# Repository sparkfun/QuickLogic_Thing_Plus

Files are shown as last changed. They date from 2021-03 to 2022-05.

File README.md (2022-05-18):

SparkFun QuickLogic Thing Plus - EOS S3
========================================

SparkFun QuickLogic Thing Plus - EOS S3 (https://www.sparkfun.com/products/17273)

[*SparkFun QuickLogic Thing Plus - EOS S3 (DEV-17273)*](https://www.sparkfun.com/products/17273)

The SparkFun QuickLogic Thing Plus [EOS&trade; S3](https://www.quicklogic.com/products/eos-s3/), is a small form factor system ideal for enabling the next generation of low-power Machine Learning (ML) devices. The QuickLogic Thing Plus is powered by QuickLogic’s EOS S3, the first eFPGA-enabled Arm Cortex&copy;-M4F MCU to be fully supported with Zephyr RTOS and FreeRTOS. Unlike other development boards which are based on proprietary hardware and software tools, the QuickLogic Things Plus is based on 100% open source hardware, compatible with the Feather form factor, and is built around 100% open source software (with support for FreeRTOS, Zephyr, nMingen, Docker, and SymbiFlow). 

Between the onboard LiPo battery connector and charging circuitry, wake-on-sound PDM microphone, and low-power, three-axis accelerometer, this Thing Plus board is ideal for wearable, voice, gesture sensing applications. The strong firmware support for the microphone and accelerator make it easy to move sensor data into the embedded FPGA. From there, you can use SensiML, TensorFlow Lite, or other tools to train and run embedded machine learning algorithms specific to your application. The board also includes a Qwiic connector to quickly interface with an ecosystem of 150+ I<sup>2</sup>C-compatible boards such as sensors, RFID readers, displays, keypads, and relays.

Repository Contents
-------------------

* **/Hardware** - Cadence design file (.brd) and scehmatic

Documentation
--------------
 
* **[Hookup Guide](https://learn.sparkfun.com/tutorials/1791)** - Basic hookup guide for the SparkFun QuickLogic EOS S3.
* **[SparkFun Graphical Datasheets](https://github.com/sparkfun/Graphical_Datasheets)** - Graphical Datasheets for various SparkFun products.

Product Versions
----------------

* [DEV-17273](https://www.sparkfun.com/products/17273) 

Version History
---------------

* v2.0 - Initial release

License Information
-------------------

This product is _**open source**_! 

Please review the LICENSE.md file for license information. 

If you have any questions or concerns on licensing, please contact technical support on our [SparkFun forums](https://forum.sparkfun.com/viewforum.php?f=152).

Distributed as-is; no warranty is given.

- Your friends at SparkFun.

_<COLLABORATION CREDIT>_

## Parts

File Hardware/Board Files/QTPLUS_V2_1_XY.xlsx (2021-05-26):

Placed Component Report
C:/PCBs/QT+/OrCAD/QTPLUS_V2.1/Board/QTPLUS_V2_1.brd
Sat May 08 19:20:52 2021
Total Placed Components: 103
REFDES | COMP_DEVICE_TYPE | COMP_VALUE | COMP_TOL | SYM_NAME | SYM_X | SYM_Y | SYM_ROTATE | SYM_MIRROR
AC1 | LIS2DH12TR_LGA50P200X200100-12N | LIS2DH12TR |  | LGA50P200X200100-12N | 29.4432 | 14.7132 | 0 | NO
C1 | CAP NP_SMD_0603_4.7UF | 4.7uF |  | SMD_0603 | 22.7235 | 11.8712 | 90 | NO
C2 | CAP NP_SMD_0402_100PF | 100pF |  | SMD_0402 | 16.5643 | 10.5281 | 180 | NO
C3 | CAP NP_SMD_0603_22UF | 22uF |  | SMD_0603 | 25.1024 | 9.9331 | 180 | NO
C4 | CAP NP_SMD_0603_4.7UF | 4.7uF |  | SMD_0603 | 12.7865 | 12.6092 | 270 | NO
C5 | CAP NP_SMD_0402_1UF | 1uF |  | SMD_0402 | 6.8619 | 21.7307 | 270 | NO
C6 | CAP NP_SMD_0402_0.1UF | 0.1uF |  | SMD_0402 | 37.9049 | 15.3563 | 90 | NO
C7 | CAP NP_SMD_0402_0.1UF | 0.1uF |  | SMD_0402 | 31.9331 | 15.2549 | 180 | NO
C8 | CAP NP_SMD_0603_4.7UF | 4.7uF |  | SMD_0603 | 37.8644 | 17.9335 | 180 | NO
C9 | CAP NP_SMD_0603_4.7UF | 4.7uF |  | SMD_0603 | 36.3514 | 17.9399 | 180 | NO
C10 | CAP NP_SMD_0402_0.1UF | 0.1uF |  | SMD_0402 | 39.8749 | 9.2727 | 90 | NO
C11 | CAP NP_SMD_0402_0.1UF | 0.1uF |  | SMD_0402 | 34.8851 | 7.4013 | 270 | NO
C12 | CAP NP_SMD_0402_12 PF | 12 pF |  | SMD_0402 | 41.8161 | 11.2781 | 180 | NO
C13 | CAP NP_SMD_0402_12 PF | 12 pF |  | SMD_0402 | 41.8075 | 13.1119 | 0 | NO
C14 | CAP NP_SMD_0402_0.1UF | 0.1uF |  | SMD_0402 | 20.3017 | 3.9249 | 180 | NO
C15 | CAP NP_SMD_0603_4.7UF | 4.7uF |  | SMD_0603 | 9.024 | 14.6535 | 180 | NO
C16 | CAP NP_SMD_0402_0.1UF | 0.1uF |  | SMD_0402 | 44.5349 | 13.4803 | 90 | NO
C17 | CAP NP_SMD_0402_0.1UF | 0.1uF |  | SMD_0402 | 46.8285 | 18.4229 | 90 | NO
C18 | CAP NP_SMD_0402_0.1UF | 0.1uF |  | SMD_0402 | 52.2349 | 14.6905 | 90 | NO
D1 | MBR0520LT3G_SOD-323_S_PMEG4005E | PMEG4005EJ,115 |  | SOD-323_S | 22.4511 | 13.1983 | 180 | NO
D2 | TPD2EUSB30DRTR_TPD2EUSB_SOTFL35 | TPD2EUSB30DRTR |  | TPD2EUSB_SOTFL35P100X50-3N | 9.5884 | 11.4381 | 180 | NO
D3 | TPD2EUSB30DRTR_TPD2EUSB_SOTFL35 | TPD2EUSB30DRTR |  | TPD2EUSB_SOTFL35P100X50-3N | 49.338 | 13.4719 | 0 | NO
D4 | TPD2EUSB30DRTR_TPD2EUSB_SOTFL35 | TPD2EUSB30DRTR |  | TPD2EUSB_SOTFL35P100X50-3N | 46.1052 | 6.7781 | 180 | NO
D5 | ESD9B3_3ST5G_SOD-323_S_SD05C.TC | SD05C.TCT |  | SOD-323_S | 52.4671 | 16.4517 | 0 | NO
FD1 | T POINT R_1_FID_IN025X033_FIDUC | fiducial |  | FID_IN025X033 | 1.545 | 17.545 | 0 | NO
FD2 | T POINT R_1_FID_IN025X033_FIDUC | fiducial |  | FID_IN025X033 | 69.045 | 6.845 | 0 | NO
H1 | MH_0_MH2_5MM_MH | MH |  | MH2_5MM | 55.7727 | 20.3481 | 0 | NO
H2 | MH_0_MH2_5MM_MH | MH |  | MH2_5MM | 2.54 | 20.3481 | 0 | NO
H3 | MH_0_MH2_5MM_MH | MH |  | MH2_5MM | 2.54 | 2.5681 | 0 | NO
H4 | MH_0_MH2_5MM_MH | MH |  | MH2_5MM | 55.7837 | 2.5681 | 0 | NO
IC1 | TPS62821DLCR_SON50P150X200X100- | TPS62821DLCR |  | SON50P150X200X100-8N | 19.9532 | 10.4252 | 0 | NO
IC2 | MCP73831T_2ACI_OT_MCP73831T_SOT | MCP73831T_2ACI_OT |  | MCP73831T_SOT95P270X145-5N | 12.1481 | 15.6992 | 90 | NO
IC3 | GD25Q16CWIGR_SON127P500X600X80- | GD25Q16CWIGR |  | SON127P500X600X80-9N-D | 24.423 | 5.4013 | 180 | NO
IC4 | 2N7002PV_115_SOTFL50P160X60-6N_ | 2N7002PV_115 |  | SOTFL50P160X60-6N | 27.5672 | 10.4381 | 180 | NO
IC5 | 2N7002PV_115_SOTFL50P160X60-6N_ | 2N7002PV_115 |  | SOTFL50P160X60-6N | 27.5672 | 12.5681 | 180 | NO
J1 | S2B-PH-SM4-TBLFSN_JST_S2B-PH-SM | S2B-PH-SM4-TBLFSN |  | JST_S2B-PH-SM4-TBLFSN | 18.17 | 18.33 | 180 | NO
J2 | CON2_CN2_CON2 | CON2 |  | CN2 | 67.0809 | 17.6972 | 90 | NO
J3 | CON2_CN2_CON2 | CON2 |  | CN2 | 67.0809 | 3.1872 | 90 | NO
J4 | 4208_QWIIC_PRT-14417_4208_QWIIC | Qwiic_PRT-14417 / 4208 |  | QWIIC_PRT-14417_4208 | 66.96 | 11.44 | 90 | NO
J5 | USB4105-GF-A_GCT_USB4105-GF-A_U | USB4105-GF-A |  | GCT_USB4105-GF-A | 2.61 | 11.42 | 270 | NO
J6 | CON16_CN16_CON16 | CON16 |  | CN16 | 51.94 | 1.27 | 0 | YES
J7 | 62201021121_CON_2X5_SMA_1P27_62 | 62201021121 |  | CON_2X5_SMA_1P27 | 51.55 | 8.9 | 180 | NO
J8 | CON18A_0_CN2X9D_FEMALE_CON18A | CON18A |  | CN2X9D_FEMALE | 59.556 | 21.591 | 90 | YES
J9 | CON12_CN12_CON12 | CON12 |  | CN12 | 24.01 | 21.59 | 180 | YES
L1 | DFE201610E_R47M=P2_DFE201610E-R | DFE201610E_R47M=P2 |  | DFE201610E-R47M_1285ASH1R0MP2 | 22.9984 | 9.5951 | 0 | NO
LED1 | APT1608SYCK_LEDC1608X85N_APT160 | APT1608SYCK |  | LEDC1608X85N | 9.1349 | 21.1084 | 90 | NO
LED2 | CON4A_P-LCC-4_67-23/R6GHBHC-B06 | 67-23/R6GHBHC-B06/2T |  | P-LCC-4 | 24.4 | 16.8 | 90 | NO
MIC_PORT | T POINT R_0P75_HOLE_T POINT R | T POINT R |  | 0P75_HOLE | 45.65 | 11.2 | 0 | NO
Q1 | NX3008CBKV_0_NX3008CBKV_SOTFL50 | NX3008CBKV_115 |  | NX3008CBKV_SOTFL50P160X60-6N | 11.8096 | 9.4519 | 0 | NO
Q2 | 2N7002KW_SOT65P210X110-3N_2N700 | 2N7002KW |  | SOT65P210X110-3N | 6.8352 | 19.4236 | 270 | NO
R1 | RESISTOR_SMD_0402_1M5 | 1M5 |  | SMD_0402 | 19.974 | 12.0801 | 270 | NO
R2 | RESISTOR_SMD_0402_453K | 453K |  | SMD_0402 | 15.1851 | 10.5383 | 0 | NO
R3 | RESISTOR_SMD_0402_100K | 100K |  | SMD_0402 | 13.7793 | 10.5417 | 180 | NO
R4 | RESISTOR_SMD_0402_100K | 100K |  | SMD_0402 | 18.0911 | 10.5717 | 180 | NO
R5 | RESISTOR_SMD_0402_200K | 200K |  | SMD_0402 | 11.2061 | 7.3183 | 180 | NO
R6 | RESISTOR_SMD_0402_10K | 10K |  | SMD_0402 | 9.7049 | 9.4483 | 0 | NO
R7 | RESISTOR_SMD_0402_100K | 100K |  | SMD_0402 | 9.6849 | 7.3183 | 0 | NO
R8 | RESISTOR_SMD_0402_1K5 | 1K5 |  | SMD_0402 | 9.1357 | 18.4545 | 180 | NO
R9 | RESISTOR_SMD_0402_4K7 | 4K7 |  | SMD_0402 | 8.8217 | 16.9425 | 90 | NO
R10 | RESISTOR_SMD_0402_10K | 10K |  | SMD_0402 | 64.4207 | 19.9785 | 180 | NO
R11 | RESISTOR_SMD_0402_10K | 10K |  | SMD_0402 | 64.3597 | 5.3685 | 180 | NO
R12 | RESISTOR_SMD_0402_10K | 10K |  | SMD_0402 | 64.4207 | 17.6385 | 180 | NO
R13 | RESISTOR_SMD_0402_10K | 10K |  | SMD_0402 | 64.3597 | 3.3315 | 180 | NO
R14 | RESISTOR_SMD_0402_10K | 10K |  | SMD_0402 | 33.3599 | 17.2951 | 0 | NO
R15 | RESISTOR_SMD_0402_10K | 10K |  | SMD_0402 | 32.0831 | 17.2915 | 0 | NO
R16 | RESISTOR_SMD_0402_1K5 | 1K5 |  | SMD_0402 | 30.4983 | 12.4569 | 270 | NO
R17 | RESISTOR_SMD_0402_22E | 22E |  | SMD_0402 | 30.4983 | 11.1623 | 270 | NO
R18 | RESISTOR_SMD_0402_22E | 22E |  | SMD_0402 | 30.4983 | 8.3641 | 270 | NO
R19 | RESISTOR_SMD_0402_1K5 | 1K5 |  | SMD_0402 | 30.4983 | 9.7487 | 270 | NO
R20 | RESISTOR_SMD_0402_10K | 10K |  | SMD_0402 | 20.3017 | 5.8249 | 180 | NO
R21 | RESISTOR_SMD_0402_10K | 10K |  | SMD_0402 | 28.6945 | 7.0849 | 180 | NO
R22 | RESISTOR_SMD_0402_10K | 10K |  | SMD_0402 | 12.5283 | 5.4143 | 270 | NO
R23 | RESISTOR_SMD_0402_10K | 10K |  | SMD_0402 | 12.6543 | 7.3183 | 0 | NO
R24 | RESISTOR_SMD_0402_100E | 100E |  | SMD_0402 | 26.6633 | 15.8383 | 0 | NO
R25 | RESISTOR_SMD_0402_100E | 100E |  | SMD_0402 | 25.4685 | 12.7417 | 180 | NO
R26 | RESISTOR_SMD_0402_220E | 220E |  | SMD_0402 | 26.7279 | 18.5483 | 0 | NO
R28 | RESISTOR_SMD_0402_100E | 100E |  | SMD_0402 | 43.7783 | 8.2003 | 270 | NO
R29 | RESISTOR_SMD_0402_4K7 | 4K7 |  | SMD_0402 | 49.3417 | 16.4361 | 90 | NO
R30 | RESISTOR_SMD_0402_10K | 10K |  | SMD_0402 | 49.3417 | 17.8503 | 90 | NO
R31 | RESISTOR_SMD_0402_4K7 | 4K7 |  | SMD_0402 | 49.3417 | 15.1243 | 90 | NO
R32 | RESISTOR_SMD_0402_22E | 22E |  | SMD_0402 | 30.9241 | 4.4183 | 0 | NO
R33 | RESISTOR_SMD_0402_22E | 22E |  | SMD_0402 | 32.3523 | 4.4183 | 0 | NO
R34 | RESISTOR_SMD_0402_10K | 10K |  | SMD_0402 | 46.2483 | 8.2385 | 270 | NO
R35 | RESISTOR_SMD_0402_10K | 10K |  | SMD_0402 | 46.2383 | 4.9567 | 270 | NO
R36 | RESISTOR_SMD_0402_22E | 22E |  | SMD_0402 | 28.1405 | 19.1583 | 0 | NO
R38 | RESISTOR_SMD_0402_22E | 22E |  | SMD_0402 | 30.7969 | 18.5183 | 0 | NO
R39 | RESISTOR_SMD_0402_100K | 100K |  | SMD_0402 | 29.5175 | 19.15 | 180 | NO
RN1 | EXB_0_EXB2HV220JV_EXB_2HV220JV | EXB_2HV220JV |  | EXB2HV220JV | 55.7132 | 14.7021 | 270 | NO
RN2 | EXB_0_EXB2HV220JV_EXB_2HV220JV | EXB_2HV220JV |  | EXB2HV220JV | 41.5547 | 5.3632 | 0 | NO
RN3 | EXB_0_EXB2HV220JV_EXB_2HV220JV | EXB_2HV220JV |  | EXB2HV220JV | 56.5632 | 8.9985 | 270 | NO
RN4 | EXB_0_EXB2HV220JV_EXB_2HV220JV | EXB_2HV220JV |  | EXB2HV220JV | 42.77 | 17.6 | 0 | NO
S1 | KMR221GLFS_KMR2_1_KMR221GLFS | KMR221GLFS |  | KMR2_1 | 16.23 | 7.98 | 0 | NO
S2 | KMR221GLFS_KMR2_1_KMR221GLFS | KMR221GLFS |  | KMR2_1 | 16.23 | 4.28 | 0 | NO
TP1 | T POINT R_TPS50_T POINT R | T POINT R |  | TPS50 | 19.3578 | 20.2515 | 0 | YES
TP2 | T POINT R_TPS50_T POINT R | T POINT R |  | TPS50 | 16.7946 | 20.2215 | 0 | YES
TP3 | T POINT R_TPS50_T POINT R | T POINT R |  | TPS50 | 14.2814 | 20.2215 | 0 | YES
TP4 | T POINT R_TPS50_T POINT R | T POINT R |  | TPS50 | 10.4464 | 5.4032 | 90 | YES
TP5 | T POINT R_TPS50_T POINT R | T POINT R |  | TPS50 | 65.05 | 1.2 | 0 | YES
TP6 | T POINT R_TPS50_T POINT R | T POINT R |  | TPS50 | 65.05 | 3.744 | 0 | YES
TP7 | T POINT R_TPS50_T POINT R | T POINT R |  | TPS50 | 10.42 | 2.835 | 90 | YES
U1 | EOS_S3B_VBGA64_VBGA64_3M5X3M5X0 | EOS_S3B_VBGA64 |  | VBGA64_3M5X3M5X0M6 | 35.05 | 11.34 | 0 | NO
U2 | AAS-B1100-H01_0_VM3011_VM3011 | VM3011 |  | VM3011 | 45.6468 | 11.1981 | 180 | NO
Y2 | ABS07-32768KHZ-T_XTAL_ABS07-327 | ABS07-32768KHZ-T |  | XTAL_ABS07-32768KHZ-T | 39.9668 | 12.2196 | 90 | NO

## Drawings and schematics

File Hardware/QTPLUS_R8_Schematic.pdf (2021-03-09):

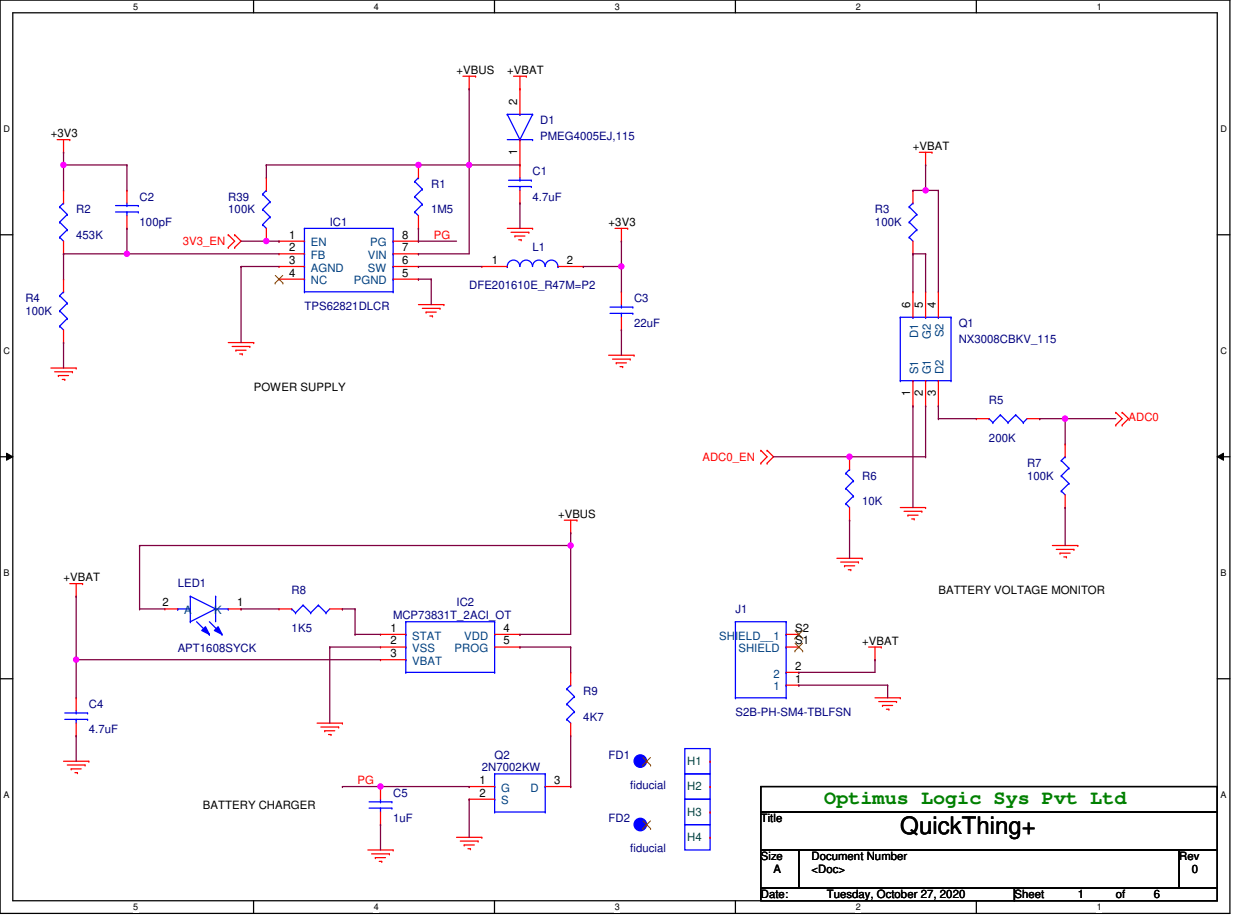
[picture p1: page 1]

Optimus Logic Sys Pvt Ltd

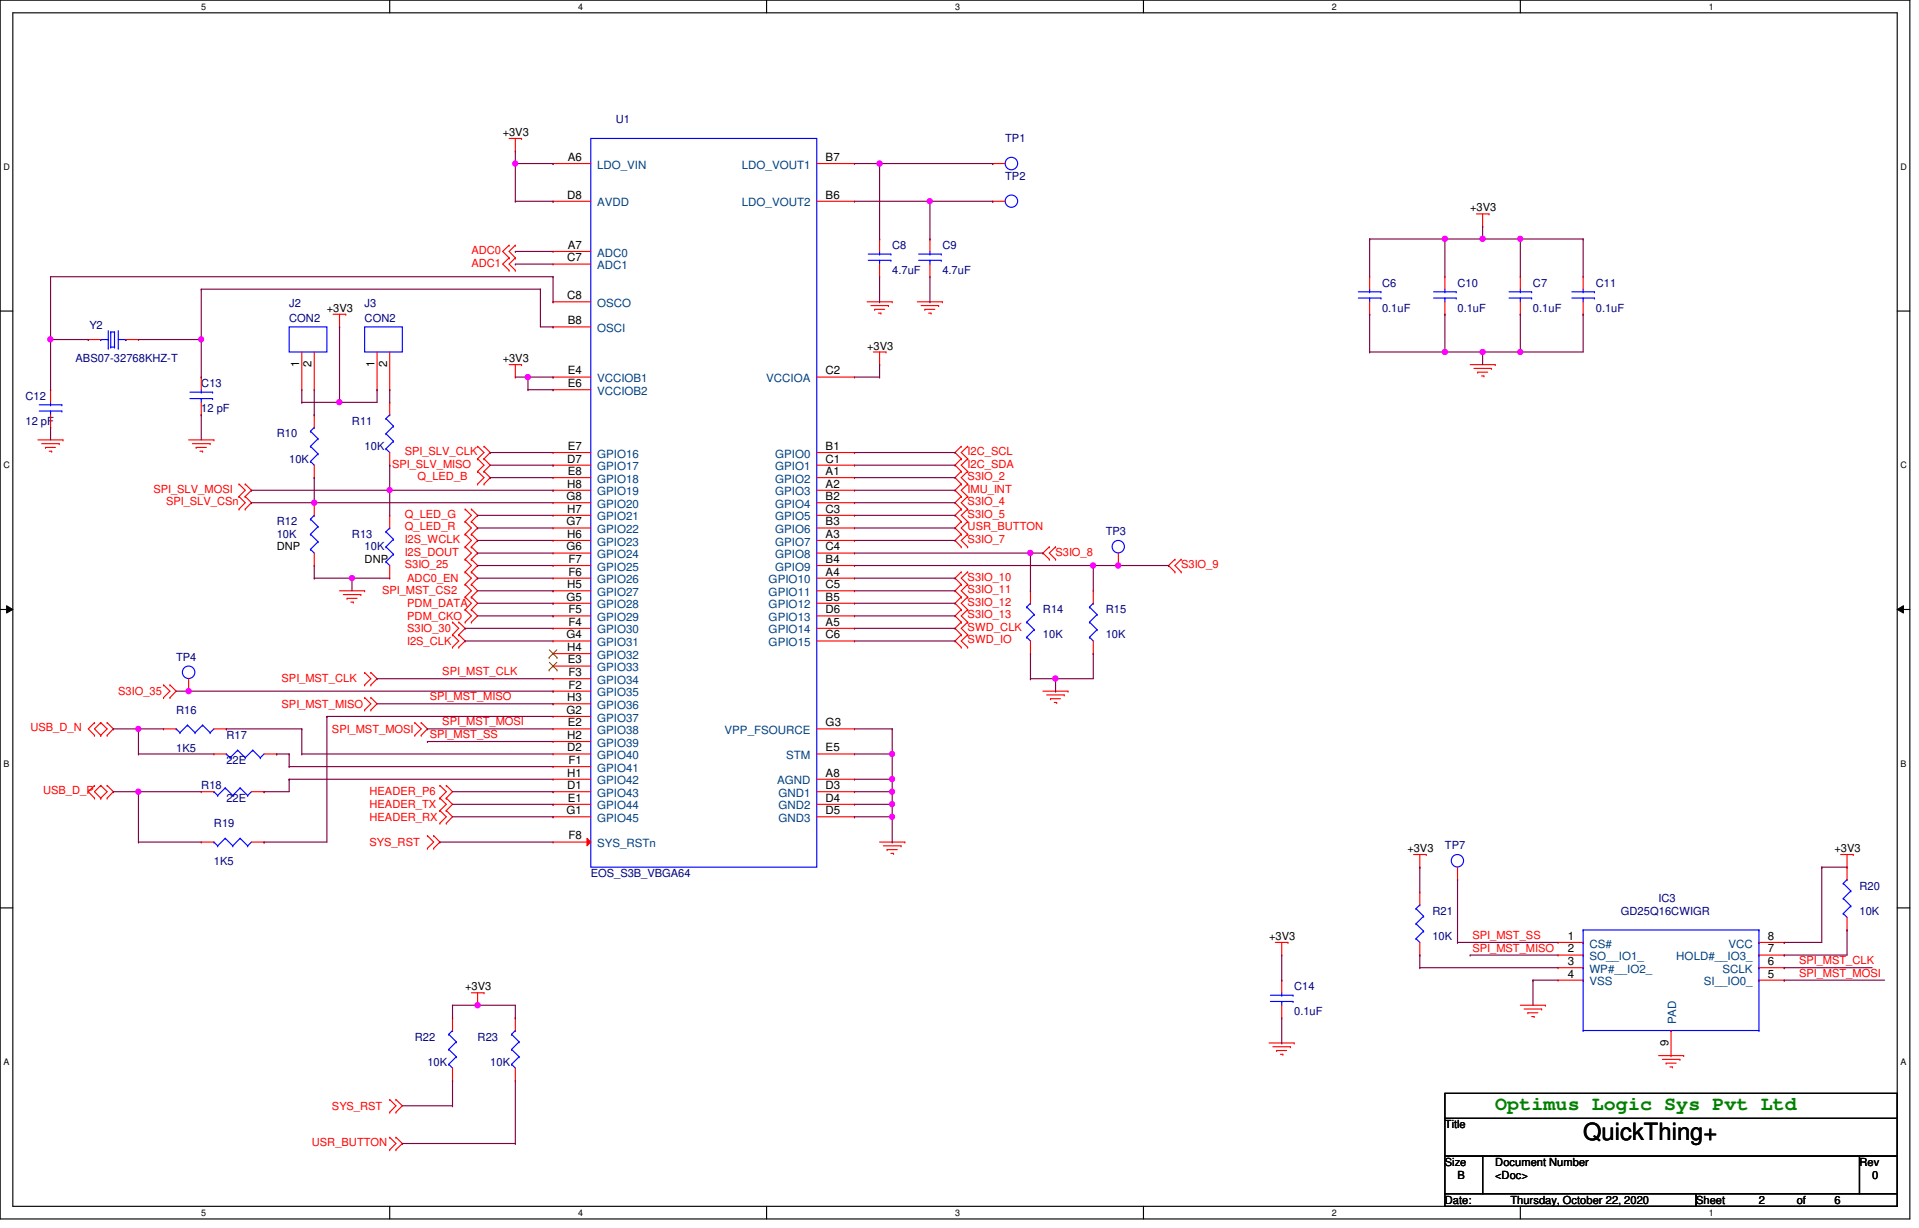
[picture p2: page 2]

Optimus Logic Sys Pvt Ltd

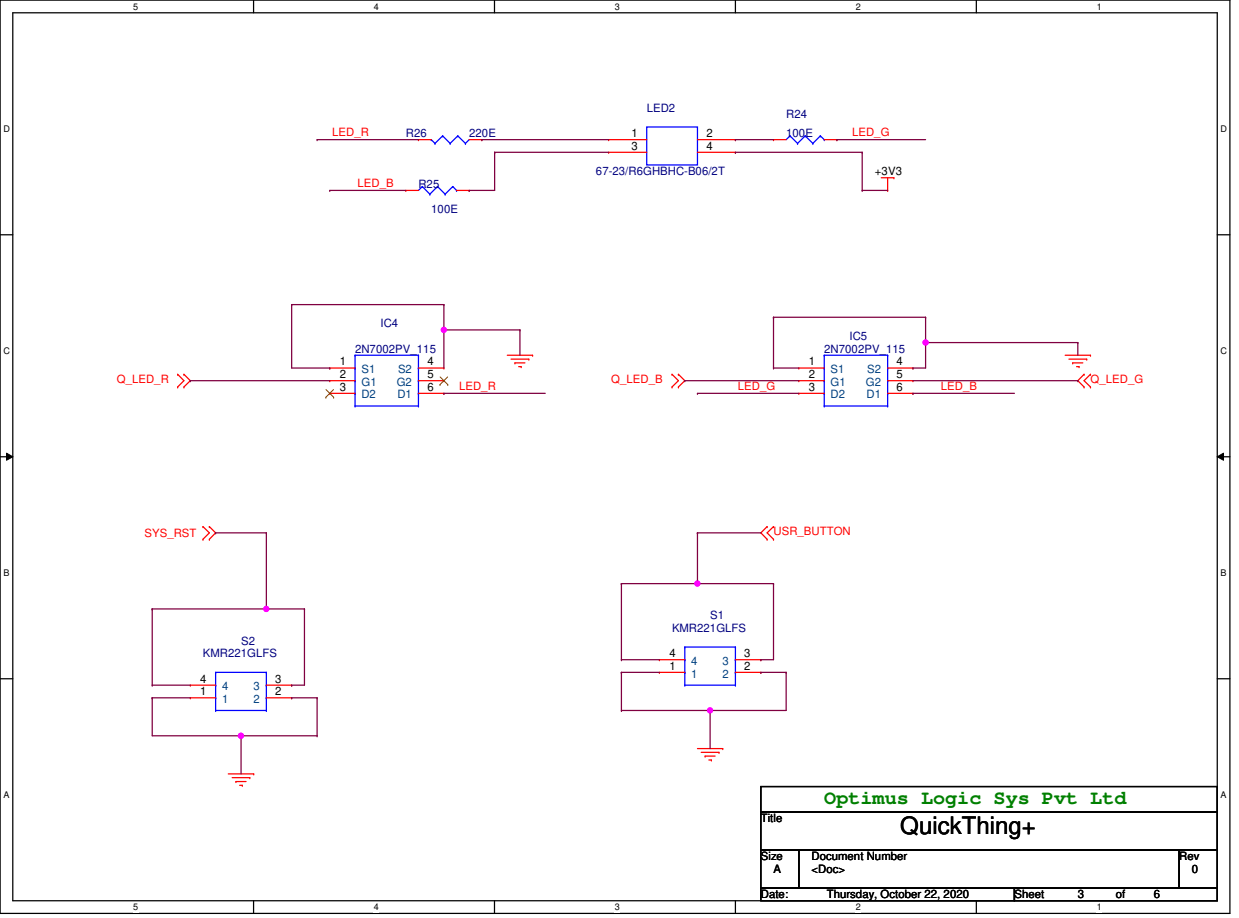
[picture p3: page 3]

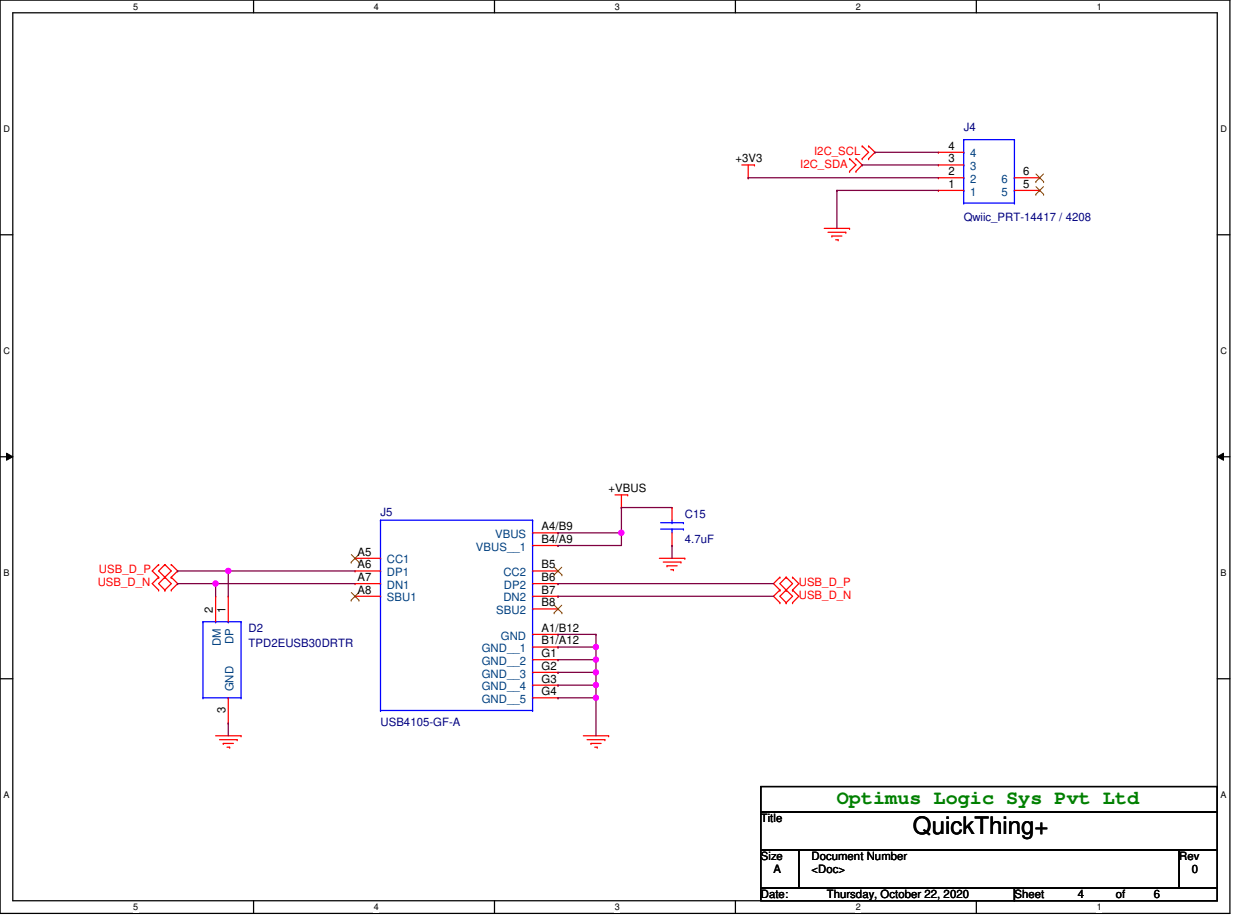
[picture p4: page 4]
Optimus Logic Sys Pvt Ltd; +VBUS; I2C_SCL I2C_SDA; USB_D_N; USB_D_P; Title; QuickThing+; Thursday, October 22, 2020; USB4105-GF-A; CC1 A5 DP1 A6 DN1 A7 SBU1 A8; VBUS; SBU2; GND; VBUS__1; GND__1; GND__2; GND__3; GND__4; GND__5; D2 DP TPD2EUSB30DRTR; Qwiic_PRT-14417 / 4208

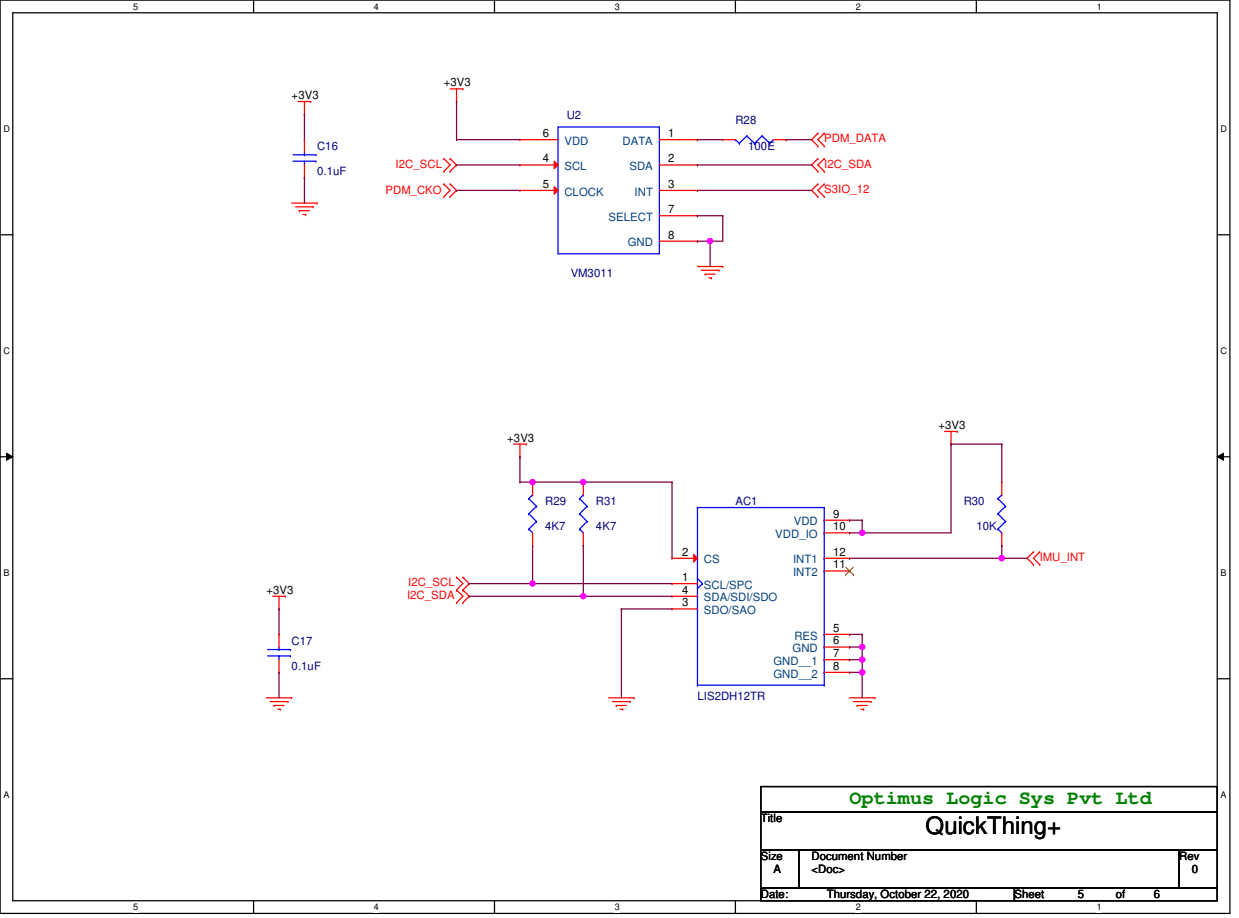
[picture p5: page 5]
Optimus Logic Sys Pvt Ltd; PDM_DATA; PDM_CKO; I2C_SCL; I2C_SDA; IMU_INT; I2C_SCL I2C_SDA; Title; QuickThing+; Thursday, October 22, 2020; LIS2DH12TR; SCL/SPC 1; SDO/SAO 3; SDA/SDI/SDO 4; RES; GND; GND__1; GND__2; VDD; VDD_IO; INT2; 11 INT1; DATA; SDA; INT; SCL 4; VDD 6; SELECT; CLOCK 5

10 | 10 11 | 11 12 | 12 13 | 13 14 | 14 15 | 15
10 | 10 11 | 11 12 | 12 13 | 13 14 | 14 15 | 15

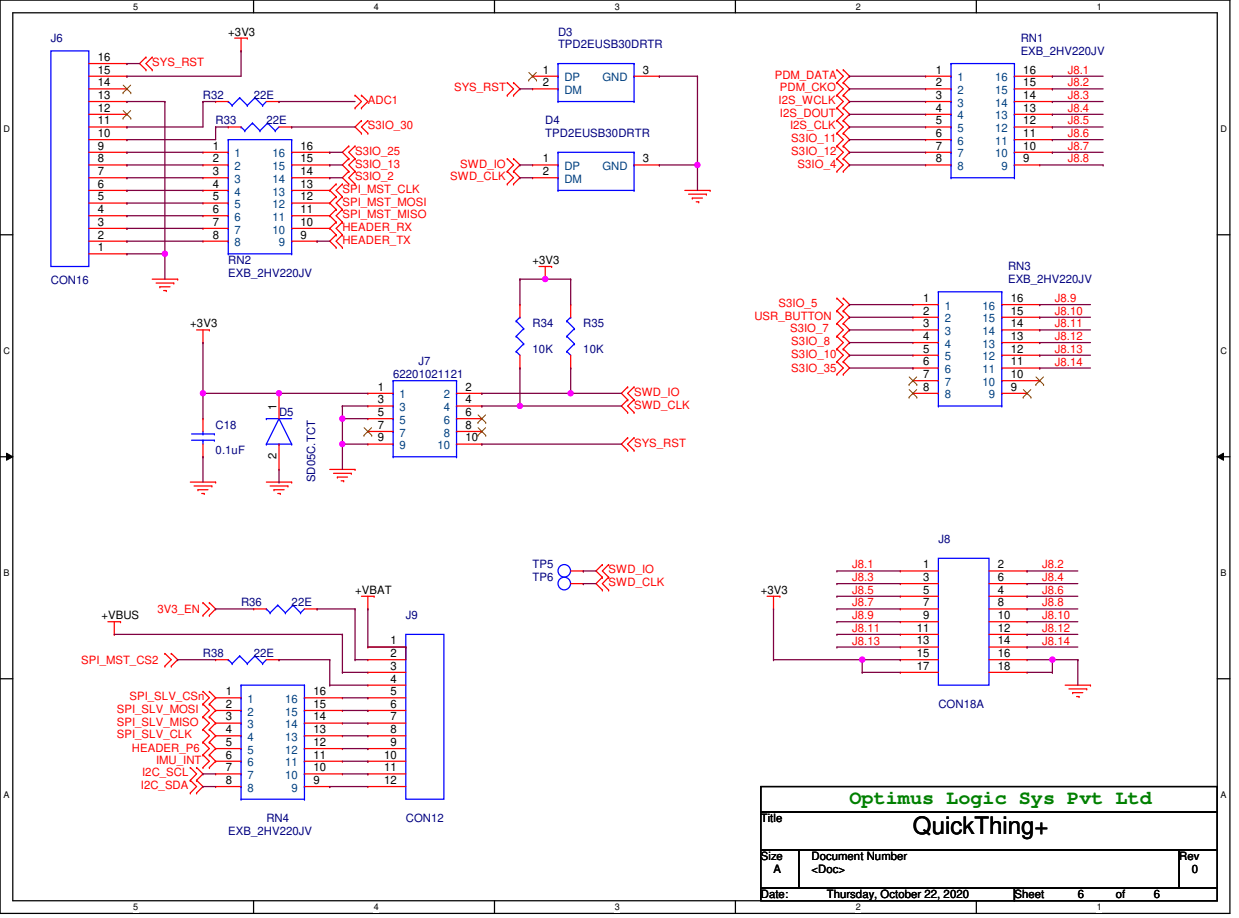
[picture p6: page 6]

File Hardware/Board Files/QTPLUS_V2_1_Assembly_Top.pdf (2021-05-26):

# ART FILM - ASSY_TOP

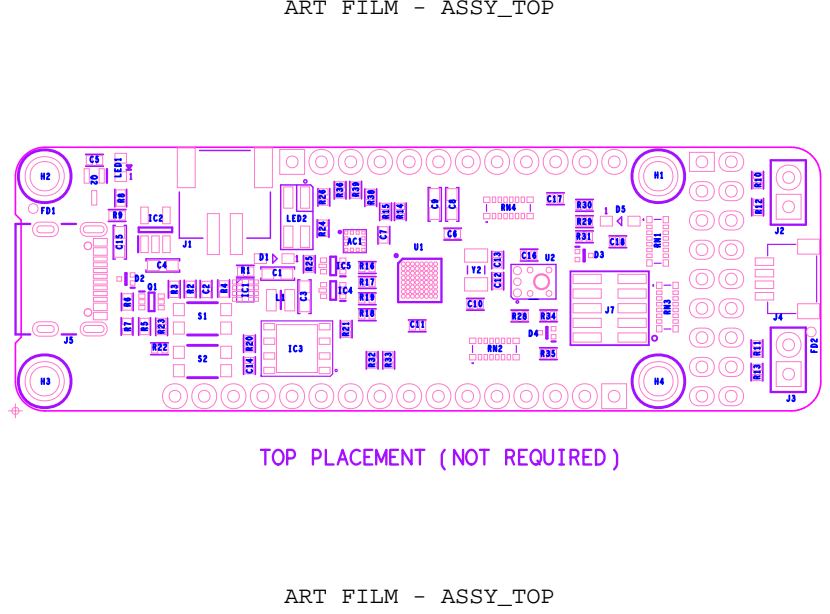
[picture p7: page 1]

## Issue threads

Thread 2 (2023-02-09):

Three broken boards

JsGraaf, 2023-02-09:
Hello,

I have three QuickLogic Thing Plusses and none of them work. Two of the three boards give a blue flashing light which turns off after 5 seconds but they can't enter programming mode (no green breathing light after pressing the usr button within 5 seconds). The other board shows a red led when powering up, which promply turns off. I have tried reflashing the bootloader with openocd and an STLinkv2, as stated on https://forum.quicklogic.com/viewtopic.php?t=29, however, the STLink is unable to restart the board after programming, failing the entire operation. I have not been able to find any resources from Sparkfun on recovering these boards and there is a "dead" thread on the forum that never got a reply.

I'm hoping that someone here can help.

Funda, 2023-02-09:
JsGraaf, thank you for reaching out here. I am investigating the issue today and will hopefully have a response to the forum thread by the end of the day. I see you replied to the thread. Let's continue the conversation there: https://forum.sparkfun.com/viewtopic.php?f=176&t=56658&p=238814&hilit=QuickLogic#p238814

Thank you!

JsGraaf, 2023-02-10:
Using a JLink mini EDU, I was able to reflash the bootloader, as stated on https://forum.quicklogic.com/viewtopic.php?t=29. This is for the "original" Quickfeather Quicklogic, but this guide is compatible. However, there is one error on the page. The git repository which contains the factory bootloader uses the name "qf_loadflash.bin" not "ql_loadflash.bin" as stated in the guide. Following the rest of the guide solved the problem for all three boards.

For those who don't have a JLink debugger and are thinking of using OpenOCD. I have tried this with a STLink V2 and got assistance in the IRC channel from someone more knowledgable. Currently, the OpenOCD drivers only support debugging and not flashing. There is no functional flash driver for the EOS S3 chip as of now (it doens't recognize the chip), which would enable OpenOCD to flash the EOS S3. This makes me believe that a JLink device is required to recover the boards.

Closed 2023-02-10.

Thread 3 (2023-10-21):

Missing USB C termination resistors so USB C to USB C cables will not work (out of spec!)

nimish, 2023-10-21:
The 2.0 board rev is missing the _required_ 5.1k pulldown resistors on the CC lines. Only type A to type C cables will work due to this: a C-to-C setup won't even get detected without CC pins terminated correctly.

https://github.com/ide/usb-c-to-c-power-mod could be a bodge fix for existing boards
